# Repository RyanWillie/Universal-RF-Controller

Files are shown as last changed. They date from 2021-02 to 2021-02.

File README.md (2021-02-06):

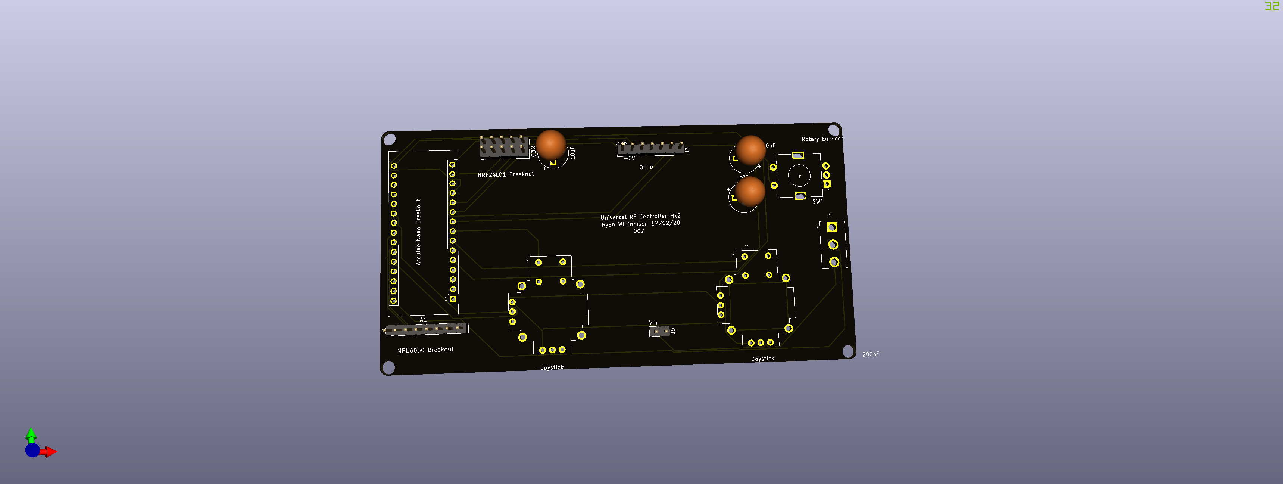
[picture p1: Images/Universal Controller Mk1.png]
Rendered PCB


# Universal-RF-Controller
As a continuation of my studies i aimed to work on a project that could utlise both aspects of my computer science and electrical engineering knowledge, as well as my interest in 3D printing. I decided upon designing an autonomous hexapod robot, which would allow for all aspects to be utilised. In order to be able to control the hexapod remotely i would require a RF controller to communicate with it wirelessly, this also presented an opportunity to tackle a much easier project first before attempting the more complex task.

  - **Computer Science** - Programming the RF Controller and creating/training the machine learning algorithms that will drive the hexapod.
  - **Electrical Engineering ** - Determining the electrical requirements, designing the circuit and PCBs, Soldering the components
  - **3D Printing** - The enclosures for both the RF Controller and the Hexapod robot are designed within Fusion360 and 3D printed using a few different materials
  
The process for designing and manufacturing the RF controller required a few revisions until it fully satisfied the design requirements they are:
  - Two joysticks for control
  - Display and rotary encoder for menu/mode selection
  - Gyroscope/accelerometer for alternative controls
  - Power switch
  - Microcontroller
  - RF Transciever
  
  ## Component Selection
  The main principle of the component selection was to use readily available components with libraries available for easy and quick setup,as well as preferring breakout boards so that the components can be easily salvaged/replaced for other projects when it is not needed. Therefore the microcontroller will be an Arduino nano, and the popular NRF24L01 transciever as the available libary makes connection extremely easy.

  **BOM**
  - Arduino Nano
  - OLED Screen
  - MPU6050 Breakout
  - Rotary Encoder
  - 2x COM09032 (Joystick)
  - 2x 200nF Capacitor
  - 10uF Capacitor
  - NRF24L01 Transciever
  - Toggle Switch

   ## Proof of concept
   Before desiging the PCB i confirmed that the designed circuit was connected correctly and worked as intended, the circuit was constructed on breadboard, this can be seen in the below image:
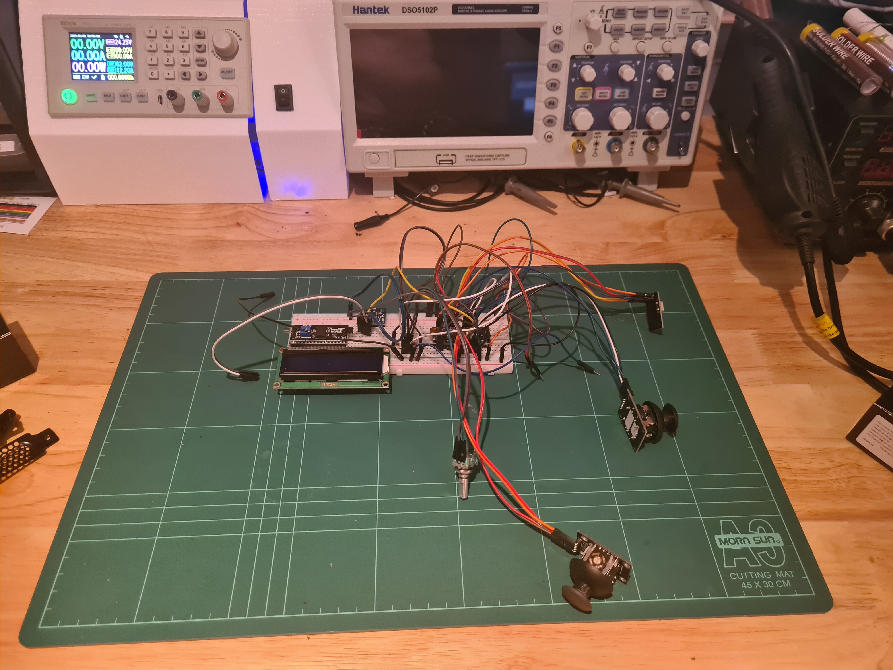
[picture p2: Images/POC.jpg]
Proof of Concept
   
   
   ## PCB Design and Manufacturing
   The open source program [KiCad](https://kicad.org/) was used as the design software for the PCB, it is a 2 layer board designed to meet JLCPCB's requirements.  As the board is a one off the space and shape requirements are purely to achieve the smallest practical footprint.
   
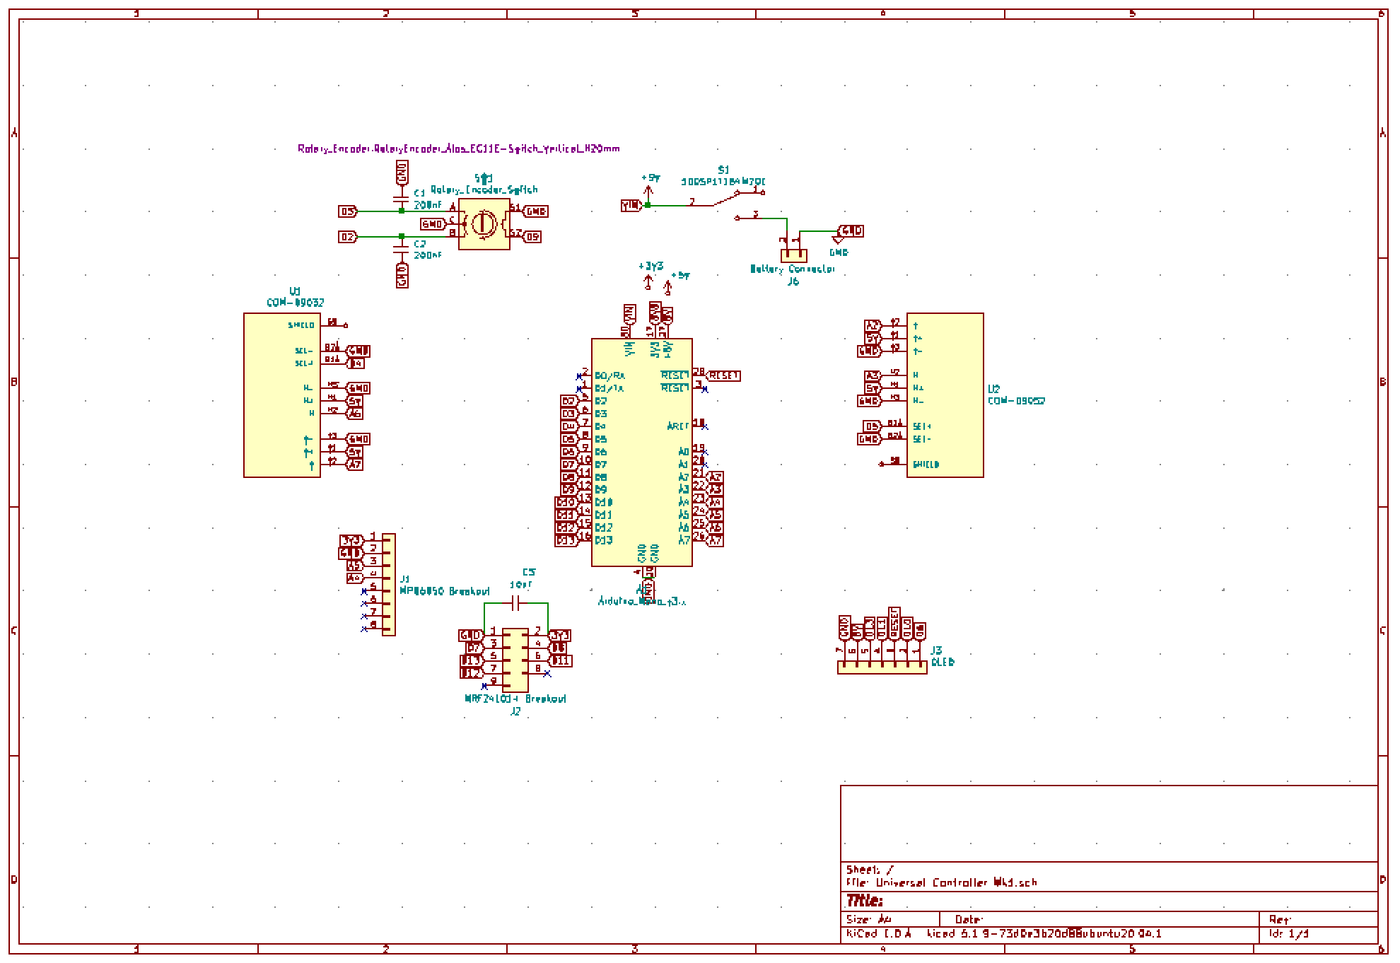
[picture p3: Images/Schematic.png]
KiCad Schematic


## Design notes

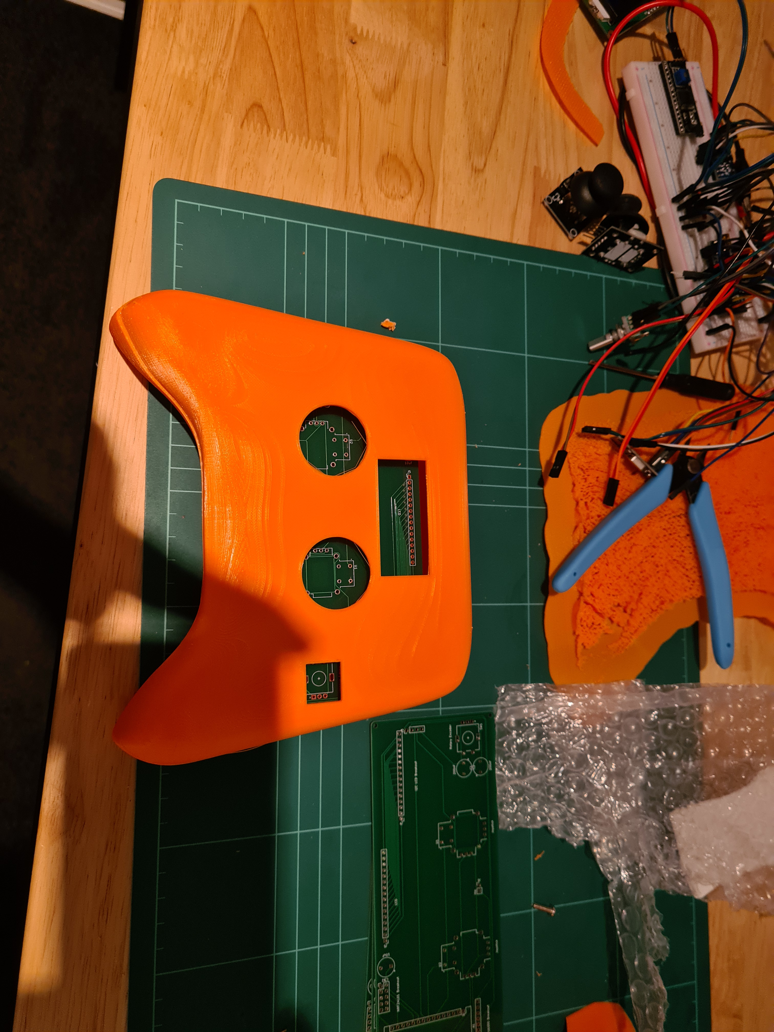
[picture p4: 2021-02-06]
Images/Mk1.jpg

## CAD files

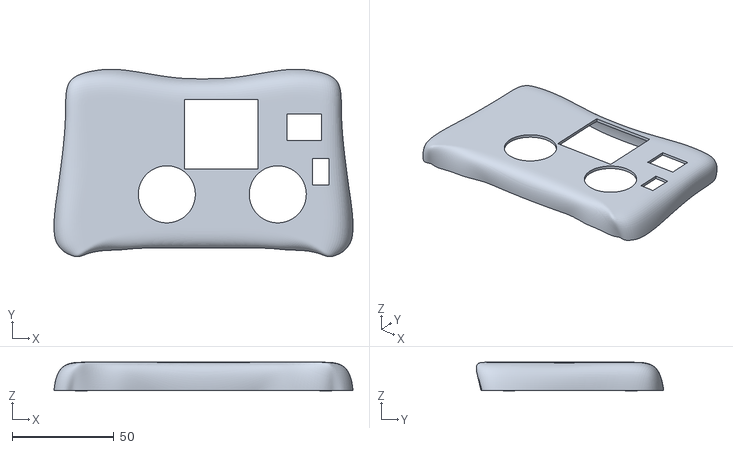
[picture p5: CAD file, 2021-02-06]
3D printed Case/Top.stl
146.7 x 92.0 x 14.0

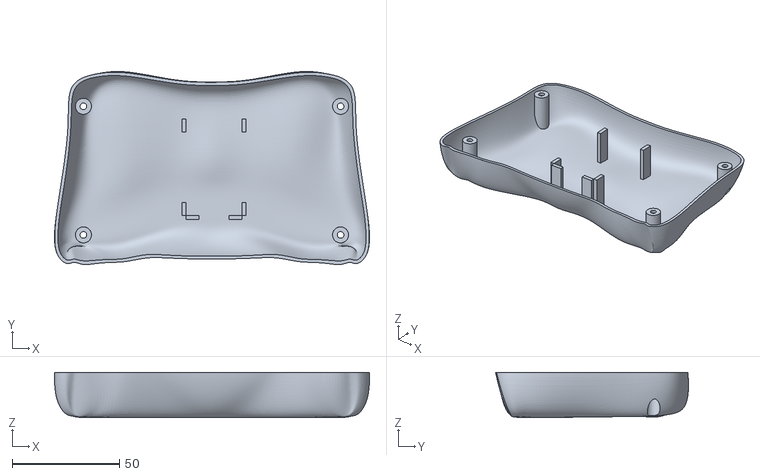
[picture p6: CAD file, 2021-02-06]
3D printed Case/Base.stl
147.0 x 90.1 x 21.2

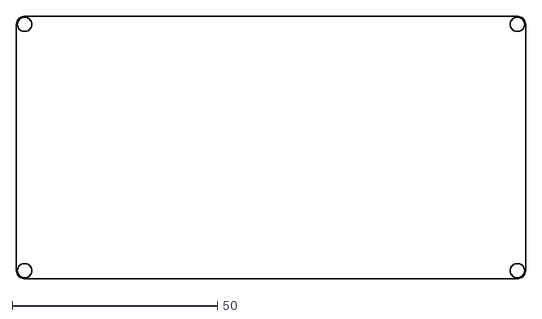
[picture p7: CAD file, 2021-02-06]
3D printed Case/UniversalControllerPCB.dxf
124.0 x 64.0

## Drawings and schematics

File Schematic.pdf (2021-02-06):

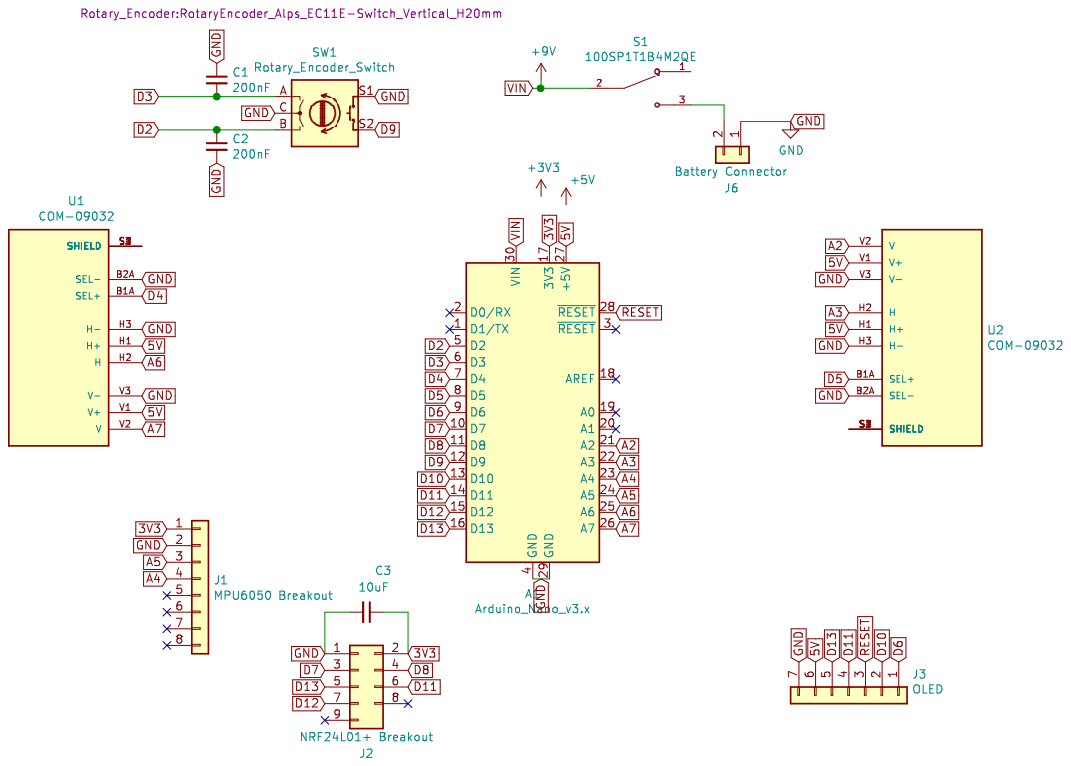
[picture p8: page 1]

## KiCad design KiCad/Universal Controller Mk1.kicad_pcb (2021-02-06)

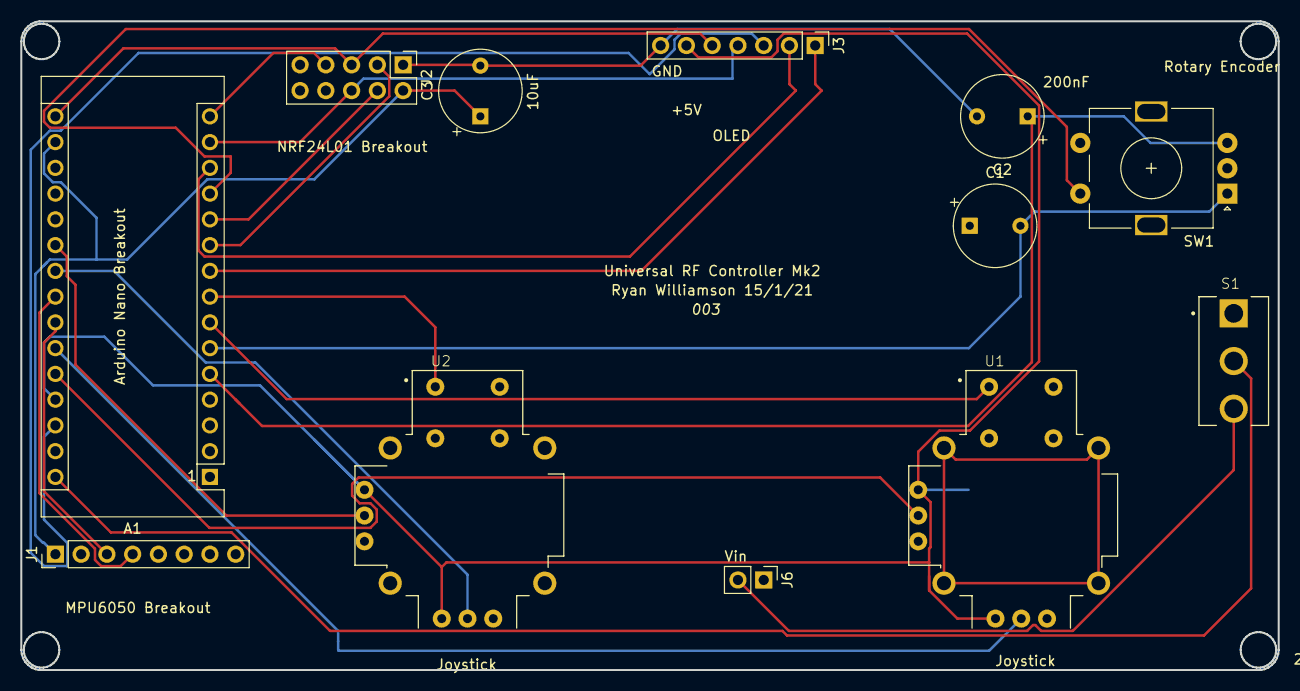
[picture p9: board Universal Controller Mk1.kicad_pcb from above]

Board: 2 copper layers, 124.0 x 64.0 mm, 12 parts (0 on the bottom side), 26 nets.

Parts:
A1: Arduino_Nano_v3.x; Arduino_Nano
C1, C2: 200nF; CP_Radial_Tantal_D8.0mm_P5.00mm
C3: 10uF; CP_Radial_Tantal_D8.0mm_P5.00mm
J1: MPU6050 Breakout; PinHeader_1x08_P2.54mm_Vertical
J2: NRF24L01+ Breakout; PinHeader_2x05_P2.54mm_Vertical
J3: OLED; PinHeader_1x07_P2.54mm_Vertical
J6: Battery Connector; PinHeader_1x02_P2.54mm_Vertical
S1: 100SP1T1B4M2QE; SW_100SP1T1B4M2QE
SW1: Rotary_Encoder_Switch; RotaryEncoder_Alps_EC11E-Switch_Vertical_H20mm
U1, U2: COM-09032; XDCR_COM-09032

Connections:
3V3: A1.17, C3.1, J1.1, J2.2
5V: A1.27, J3.6, U1.H1, U1.V1, U2.H1, U2.V1
A2: A1.21, U2.V2
A3: A1.22, U2.H2
A4: A1.23, J1.4
A5: A1.24, J1.3
A6: A1.25, U1.H2
A7: A1.26, U1.V2
D2: A1.5, C2.1, SW1.B
D3: A1.6, C1.2, SW1.A
D4: A1.7, U1.B1A
D5: A1.8, U2.B1A
D6: A1.9, J3.1
D7: A1.10, J2.3
D8: A1.11, J2.4
D9: A1.12, SW1.S2
D10: A1.13, J3.2
D11: A1.14, J2.6, J3.4
D12: A1.15, J2.7
D13: A1.16, J2.5, J3.5
GND: A1.4, A1.29, C1.1, C2.2, C3.2, J1.2, J2.1, J3.7, J6.1, SW1.C, SW1.S1, U1.B2A, U1.H3, U1.V3, U2.B2A, U2.H3, U2.V3
unnamed: J6.2, S1.3
unnamed: U1.S1, U1.S2, U1.S3, U1.S4
unnamed: U2.S1, U2.S2, U2.S3, U2.S4
RESET: A1.28, J3.3
VIN: A1.30, S1.2

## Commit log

2021-02-06 Controller Mk2 design files and images
    [Base.stl, Top.stl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]
2021-02-06 Adding in schematic Image
